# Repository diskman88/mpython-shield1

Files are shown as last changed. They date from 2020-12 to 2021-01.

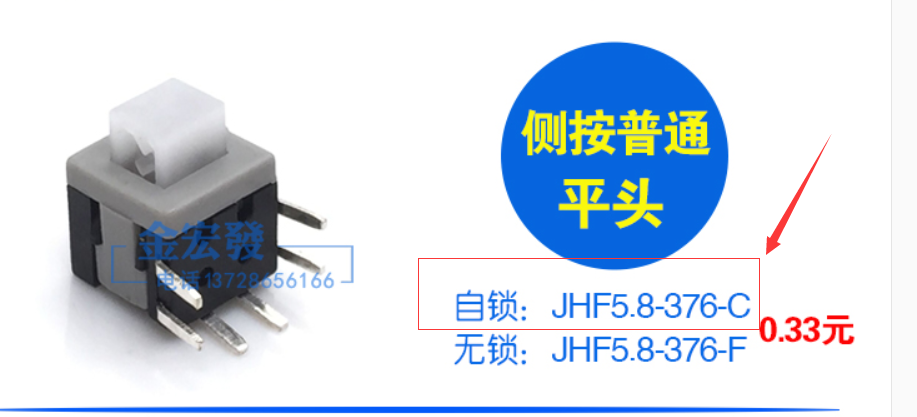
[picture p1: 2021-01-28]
1_Hardware/V2.1.1/datasheet/开关5.png

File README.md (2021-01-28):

# 掌控板拓展板Ⅰ

| 目录 | 说明 | 
| :---  | :---|
| 1_Hardware | 产品原理图及PCB设计工程文件 |
| 2_Firmware | 主从MCU固件源码或bin文件 |
| 3_Software | 配合产品使用或生产用到的软件程序 |
| 4_Examples | 用户应用层相关的源码(含示例) |
| 5_Docs | 产品相关文档(含产品规格书、测试文档)、产品外观结构及包装结构或尺寸图、对外宣传推广效果图片资源  |

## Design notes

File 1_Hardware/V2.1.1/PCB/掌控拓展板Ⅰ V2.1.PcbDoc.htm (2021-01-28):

Reporting Options

# File in Previous Format

Date | : | 2021/1/28
Time | : | 9:38:10
Filename | : | E:\3-micropython\1-esp32\2-掌控扩展板\掌控板扩展板Ⅰ\mpython-shield-1\1_Hardware\V2.1.1\PCB\掌控拓展板Ⅰ V2.1.PcbDoc

Version | Warning

This file was generated by an earlier version of the software

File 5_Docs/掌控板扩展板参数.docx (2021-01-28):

掌控板扩展板参数

片上资源：

板载锂电池，锂电充电电路，音频功放及喇叭输出，DC马达驱动，可外接两个马达，两路I2C输出，12路扩展IO接口。

主要参数：

工作电压：DC3.3V

喇叭最大输出功率：1W

外接DC马达数量：2个

马达最大驱动电流：150mA

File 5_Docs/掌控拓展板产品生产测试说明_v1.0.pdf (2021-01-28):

掌控拓展板

Product Datasheet | 1 | 盛思研发@2017

### 1 概述

掌控拓展板是 mPython 掌控板衍生的一款体积小巧、易于携带。支持电机驱动、语音播放、 语音合成等功能的 IO 引脚扩展板,可扩展 12 路 IO 接口和 2 路 I2C 接口。

### 2 技术参数

该板具有以下特性:

- 驱动工作电压：3.6 ～ 5.2V
- 两路 DC 马达驱动,单路电流 150mA
- 支持音频功放和喇叭输出
- 支持文字转语音(Text To Speech)的语音合成
- 扩展 12 路 IO 接口、2 路 I2C 接口
- 体积小巧、便携,易于携带
- 支持锂电池供电和外接 USB 电源供电两种方式
- 内置 350mAH 锂电池,支持锂电池循环充电
- 工作电压:3.3V
- 最大输出电流: `1A@3.3V`

### 3 生产资料

3.1焊接
需要焊接的有喇叭,电锂电池,排针,压针

要求:
1.焊点饱满,圆润,光滑
2.压针须垂直,无倾斜,位置无偏移.
3.喇叭和电池焊接完成后,须用 3M 胶固定在板上,牢固.

3.2烧录
使用工具:软件 STVP,ST-LINK 烧录器

Step1.打开 stvp,硬件选择 ST-LINK,SWIM,STM8S103F3

Step2.需要烧录 PROGRAM MEMORY 和 OPTION BYTE 两页数据,分别依次加入 STM8S103F3P （TSSOP20)-掌控拓展板 Ⅰ(3.7v) v1.0.hex 和 optionbit.hex

掌控拓展板

Product Datasheet | 2 | 盛思研发@2017

Step3.确认 Memory checksum 是否正确.该固件 checksum 为 PROGRAM MEMORY(0x7A191), PROGRAM MEMORY(0x251)

Step4.选择 program all table,烧录所有页.成功后,提示框提示成功烧录信息.

3.3生产测试
使用工具:烧录架和 usb 电流表
测试项目 | 测试步骤 | 判断条件
喇叭测试 | 1. 将测试板放入测试架上,下压 2. 打开拓展板开关 | 蜂鸣器先发出 1KHz 声音,再(低至高, 高至低)扫频 20hz~20Khz. 要求:声音清脆,无异响,频率正常
电机驱动 | 确认两电机是否转动 | 两电机可转动,并转动力矩有力.
3.3V 电压 | 确认显示屏电压值 | 正确应显示 3.3V,其他均异常
锂电池电压 | 接入 usb 线至拓展板 usb 接口,确 认测试架,电压表显示 | 应能显示锂电池实际电压值,锂电池 电压依实际电池状况而不同,一般在 3.5~4.35V,超出为异常
充电电流 | Usb 线串入电流表插入 usb 接口, 测试针起来,确认电流值 | 电流表显示充电电流值正常,充电电 流依锂电池状态有所不同.具体数据 根据实际生产.
指示灯 | 确认电源,充电指示灯是否正常 | 指示灯可亮

### 4 修订版本

Version | Note | Date
V1.0 | 初定 | 2019.03.05

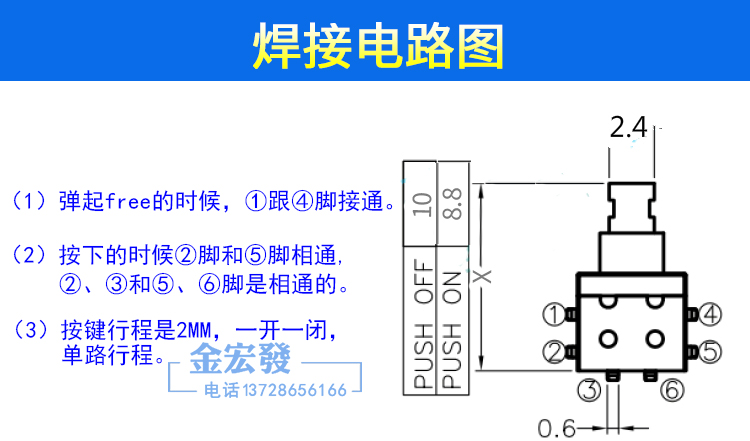
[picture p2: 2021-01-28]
1_Hardware/V2.1.1/datasheet/电源开关3.jpg

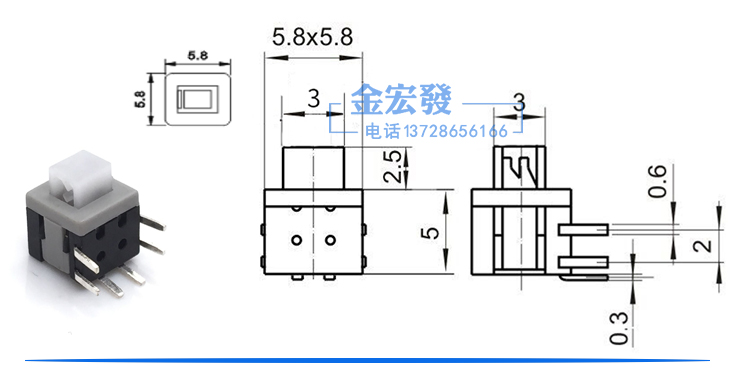
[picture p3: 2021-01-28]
1_Hardware/V2.1.1/datasheet/电源开关4.jpg

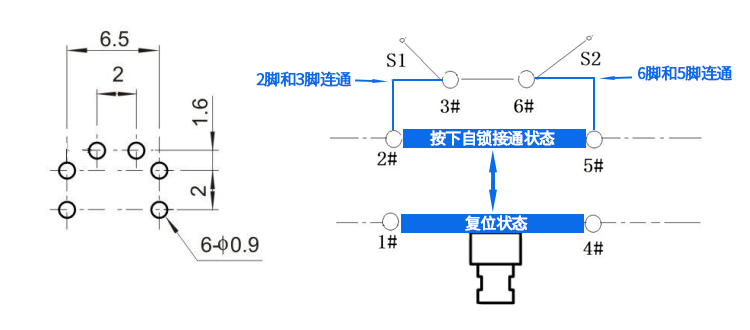
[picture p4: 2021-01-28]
1_Hardware/V2.1.1/datasheet/电源开关5.jpg

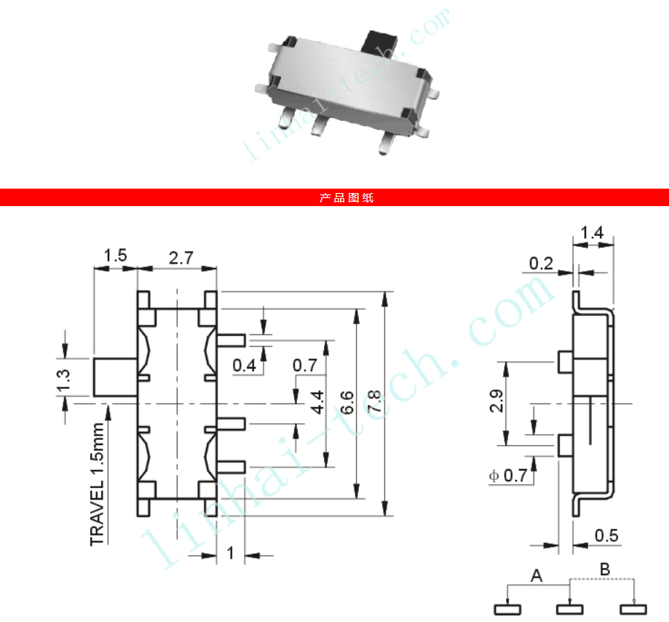
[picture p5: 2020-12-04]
1_Hardware/V2.1.1/datasheet/拨动开关.png

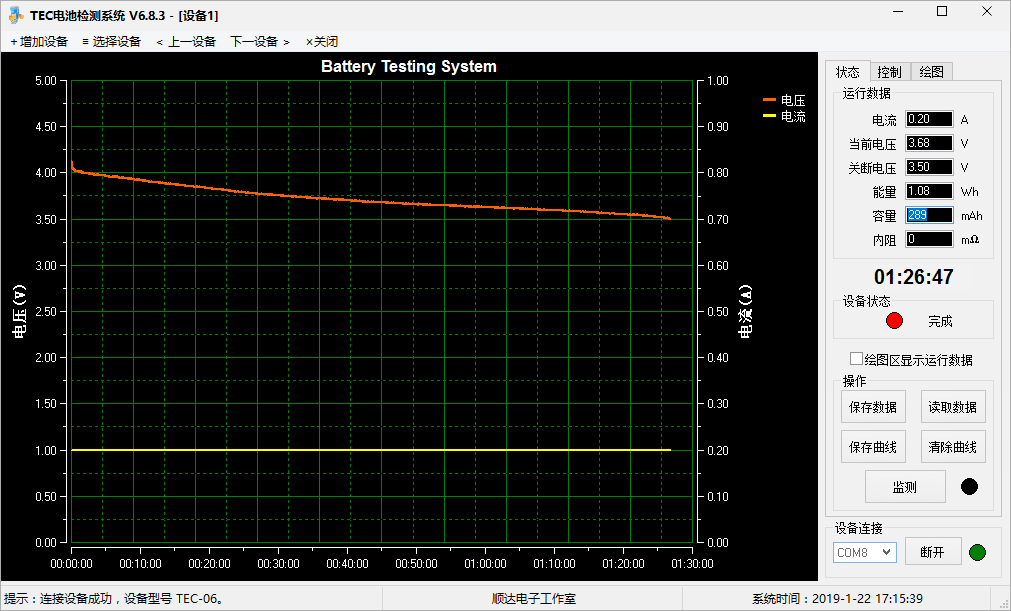
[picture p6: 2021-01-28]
5_Docs/华为电池2.png

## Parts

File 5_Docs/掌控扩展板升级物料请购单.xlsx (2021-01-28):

单号：
盛思工厂
手工请购单
页次：
1/1
单据日期： 2020-12-28 申请人： 蒋朝晖 审核码： 已审核 请购日期： 2020-12-28 申请部门： 研发二部 请购类型： 其他
序号 | 品号 | 品名 | 规格 | 请购数量 | 请购单 位 | 需求日期 | 紧急 | 参考供应商
1 | 50090 | 三极管 | 型号：MMBT3906LP-7 PNP 集电极最大工作电流：200mA 集射极击穿电压Vce:40V 封装：DFN-3L | 100 | PCS | 2021-01-02 |  | https://so.szlcsc.com/global.html?k=MMBT3906%2520DFN&hot-key=%E9%92%BD%E7%94%B5%E5%AE%B9TC212A106K016Y
仓库：
制单：
核准：

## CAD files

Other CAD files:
2_Firmware/发布固件/STM8S103F3P（TSSOP20)-掌控拓展板 Ⅰ(3.8v) 固件_v2.1.0/STM8S103F3P（TSSOP20)-掌控拓展板 Ⅰ(3.8v) v2.1.0.stp

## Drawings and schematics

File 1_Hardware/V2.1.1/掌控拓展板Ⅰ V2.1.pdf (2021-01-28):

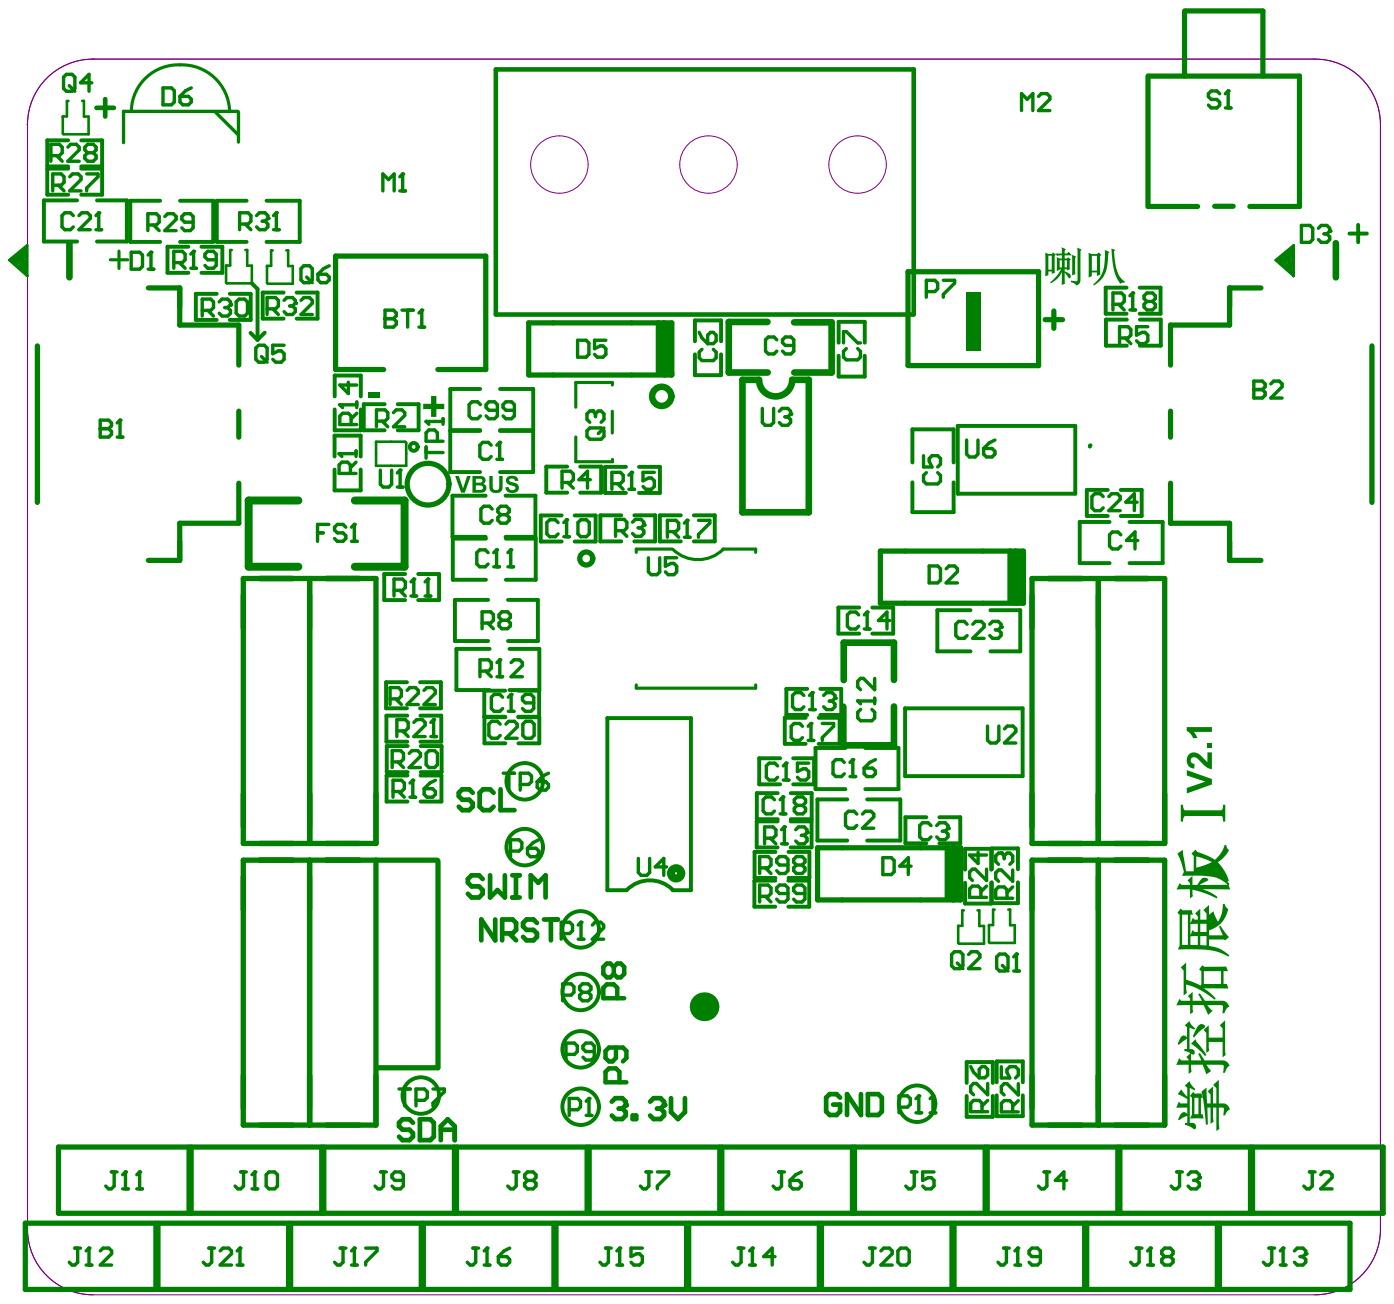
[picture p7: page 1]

Board St

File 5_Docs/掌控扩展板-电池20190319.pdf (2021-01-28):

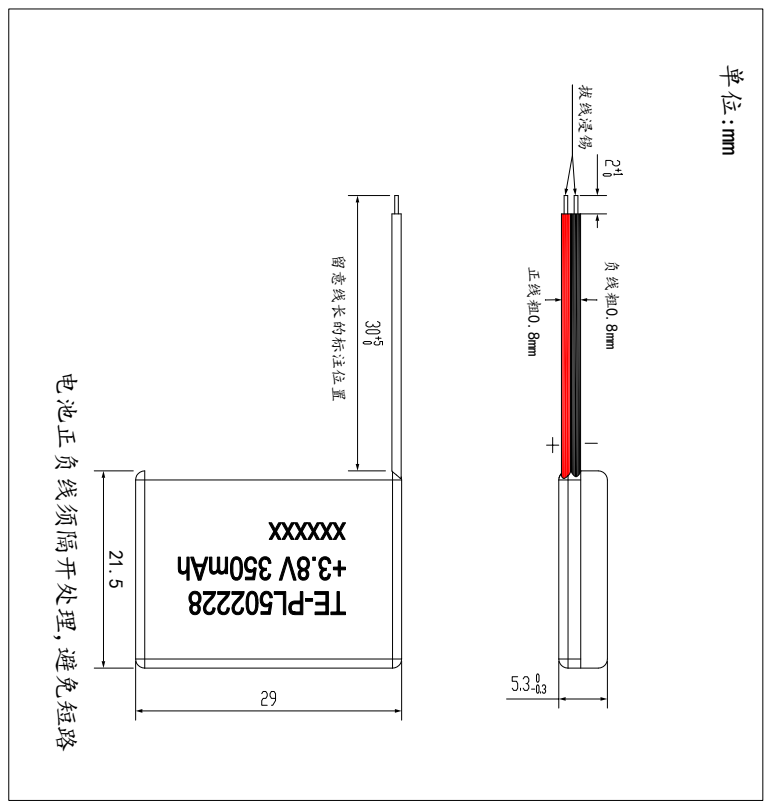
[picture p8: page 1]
留意线长的标注位置; 拔线浸锡; 电池正负线须隔开处理,避免短路; 负线粗0.8mm; 正线粗0.8mm

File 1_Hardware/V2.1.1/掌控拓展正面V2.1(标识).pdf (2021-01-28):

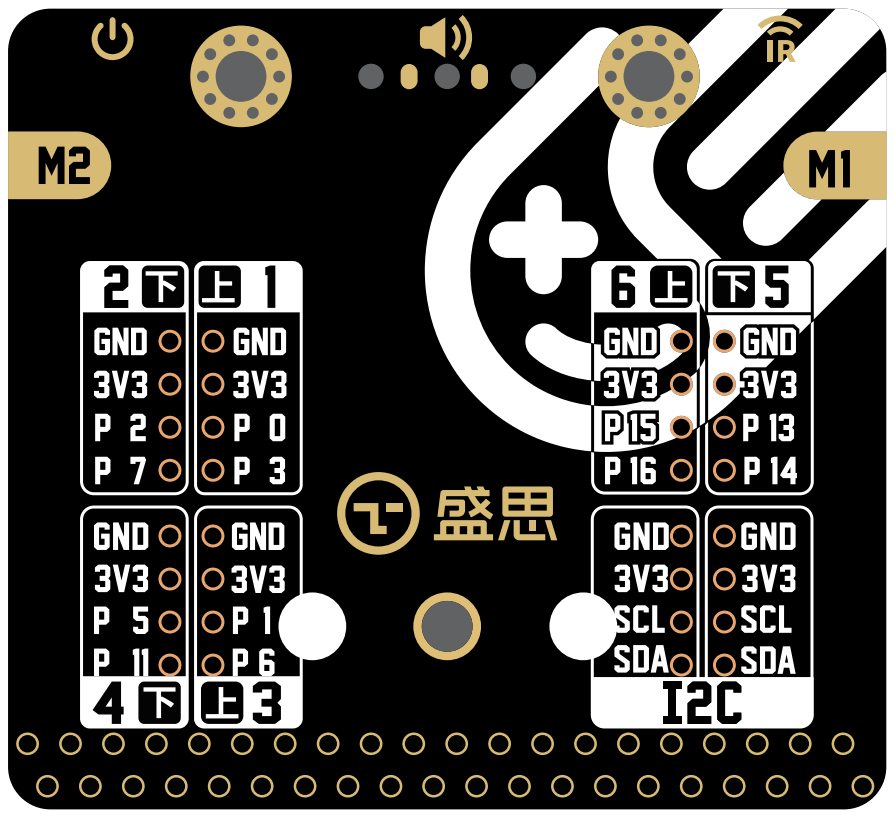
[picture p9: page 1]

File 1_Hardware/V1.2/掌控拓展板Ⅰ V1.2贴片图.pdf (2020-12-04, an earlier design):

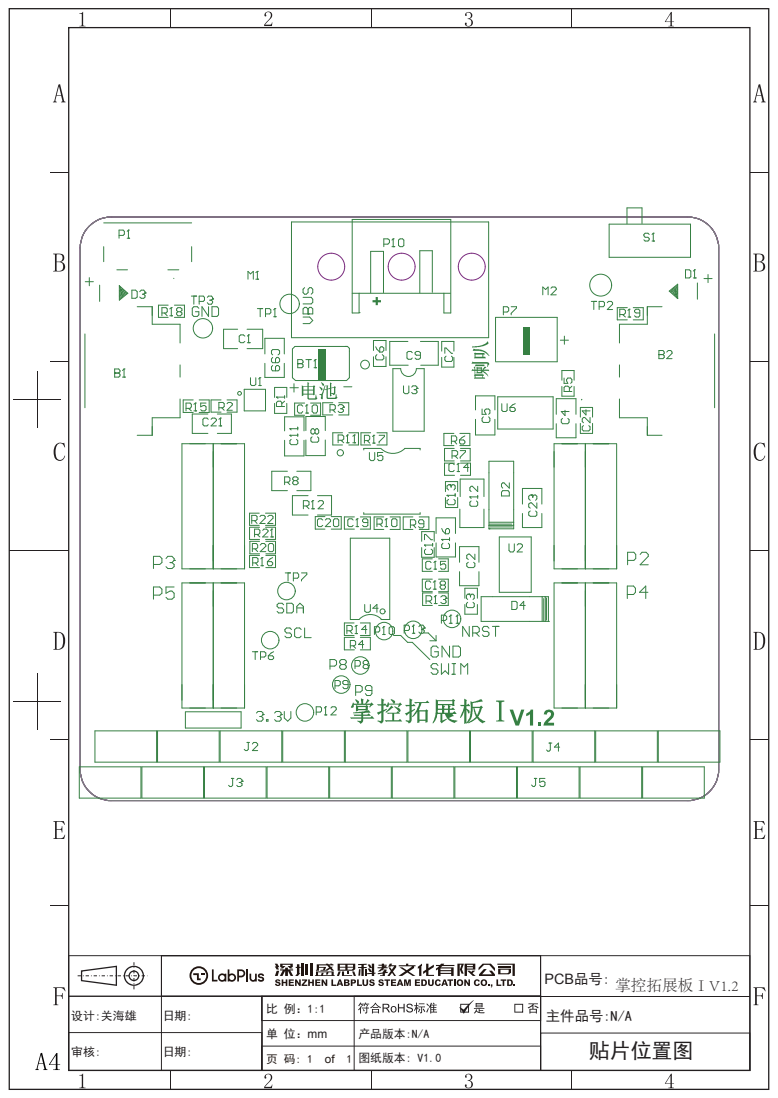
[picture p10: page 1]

PCB品号: 掌控拓展板ⅠV1.2

设计:关海雄 | 日期: | 比 例：1:1 | | | 主件品号:N/A

单 位：mm | 产品版本:N/A

审核: | 日期: | 贴片位置图

页 码: 1 of 1 | 图纸版本: V1.0

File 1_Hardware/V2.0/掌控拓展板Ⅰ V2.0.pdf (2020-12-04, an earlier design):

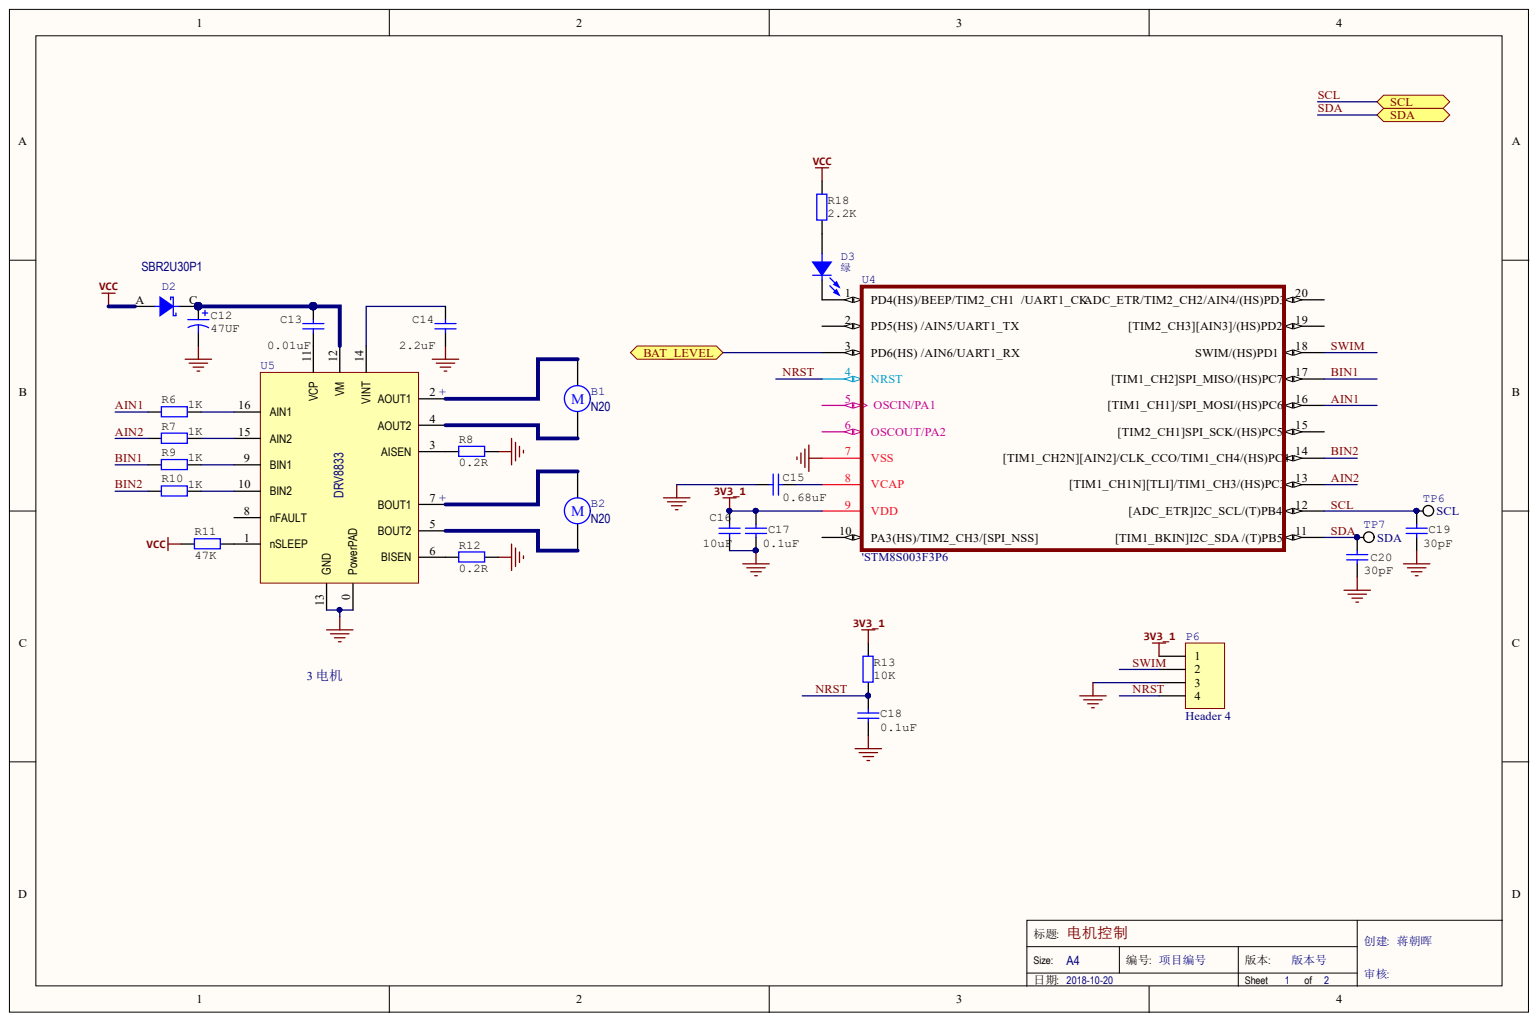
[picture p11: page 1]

电 机 控 制 标题 : | 创建 : 蒋朝晖 审核 :

Size: A4 | 编号 : 项目编号 | 版本 : 版本号

日期 : 2018-10-20 | | Sheet of

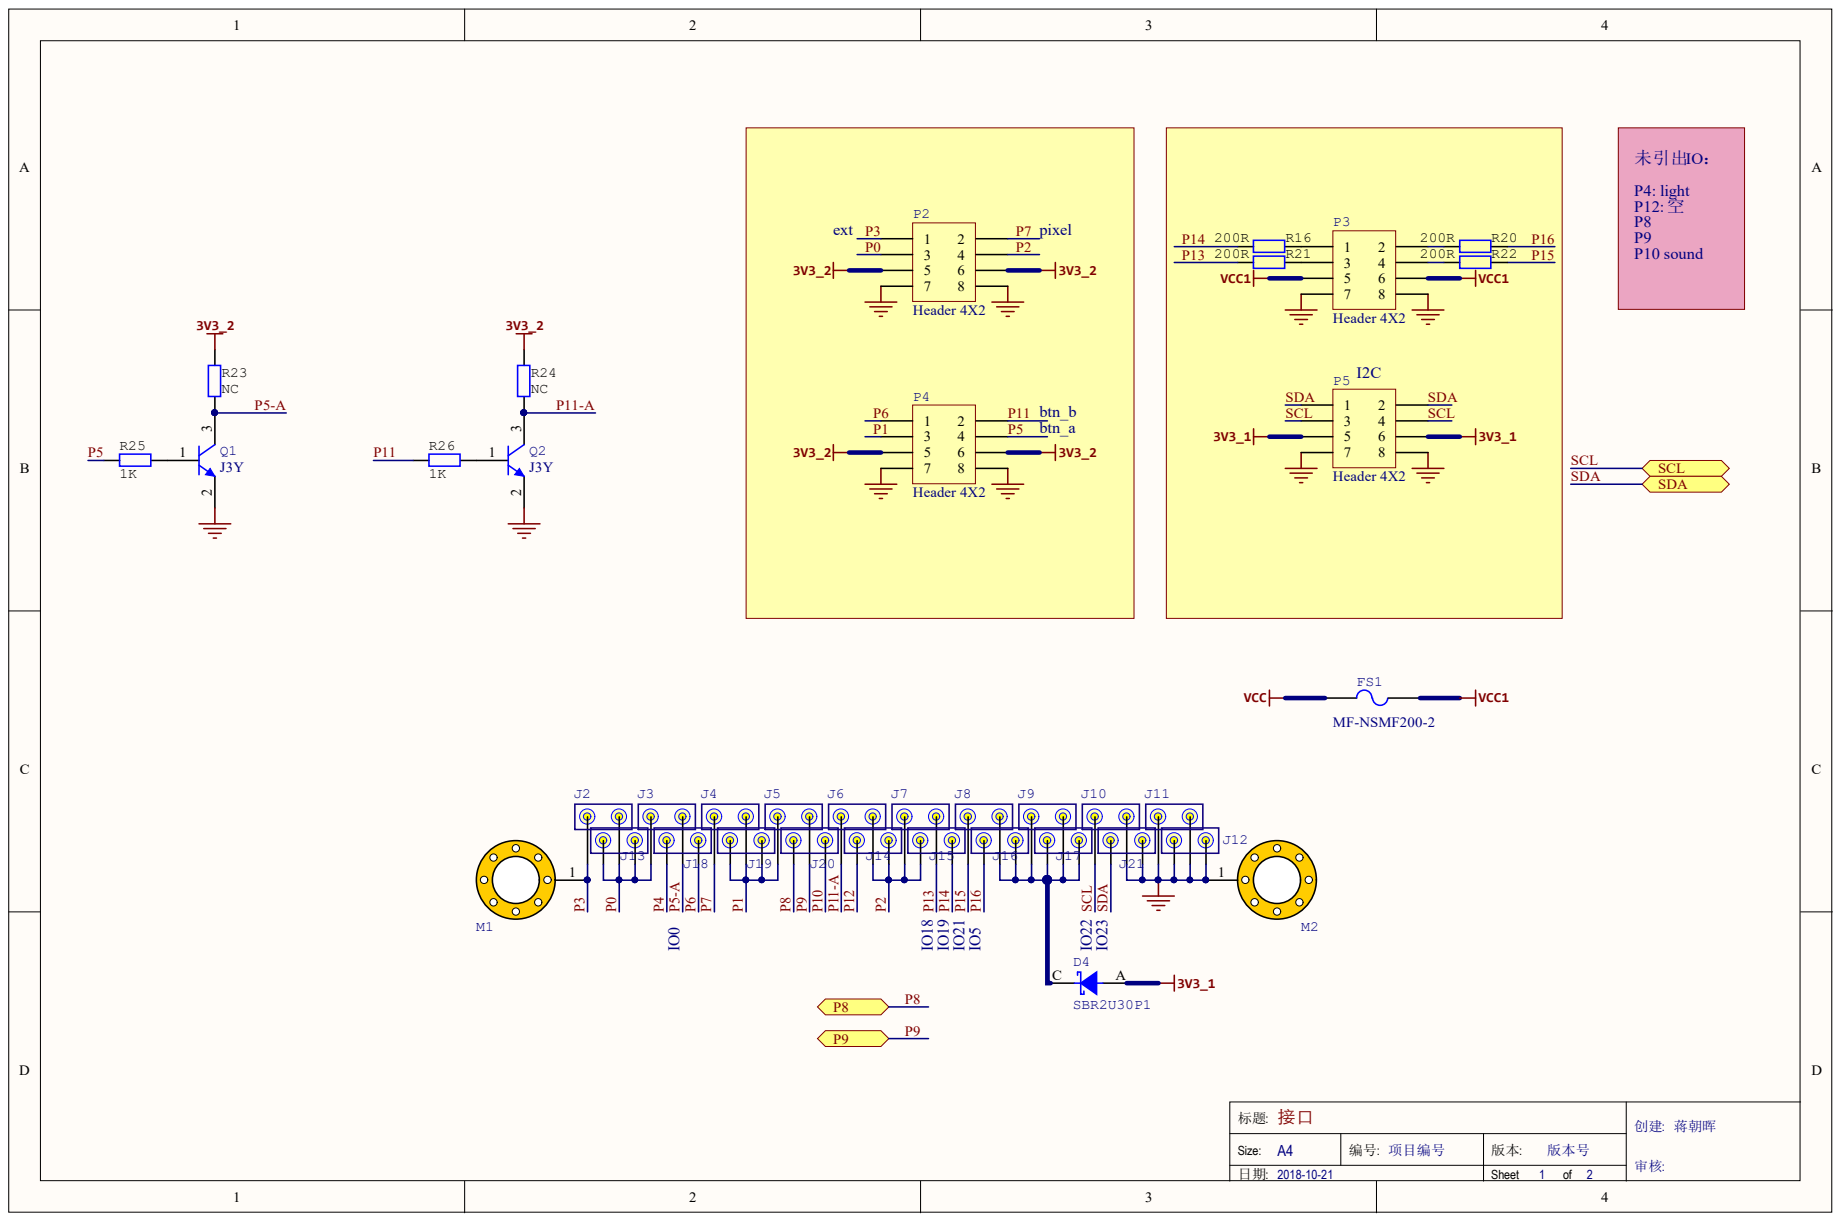
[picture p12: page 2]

接口 标题: | 创建: 蒋朝晖

Size: A4 | 编号: 项目编号 | 版本: 版本号
日期: | | | 审核: 2

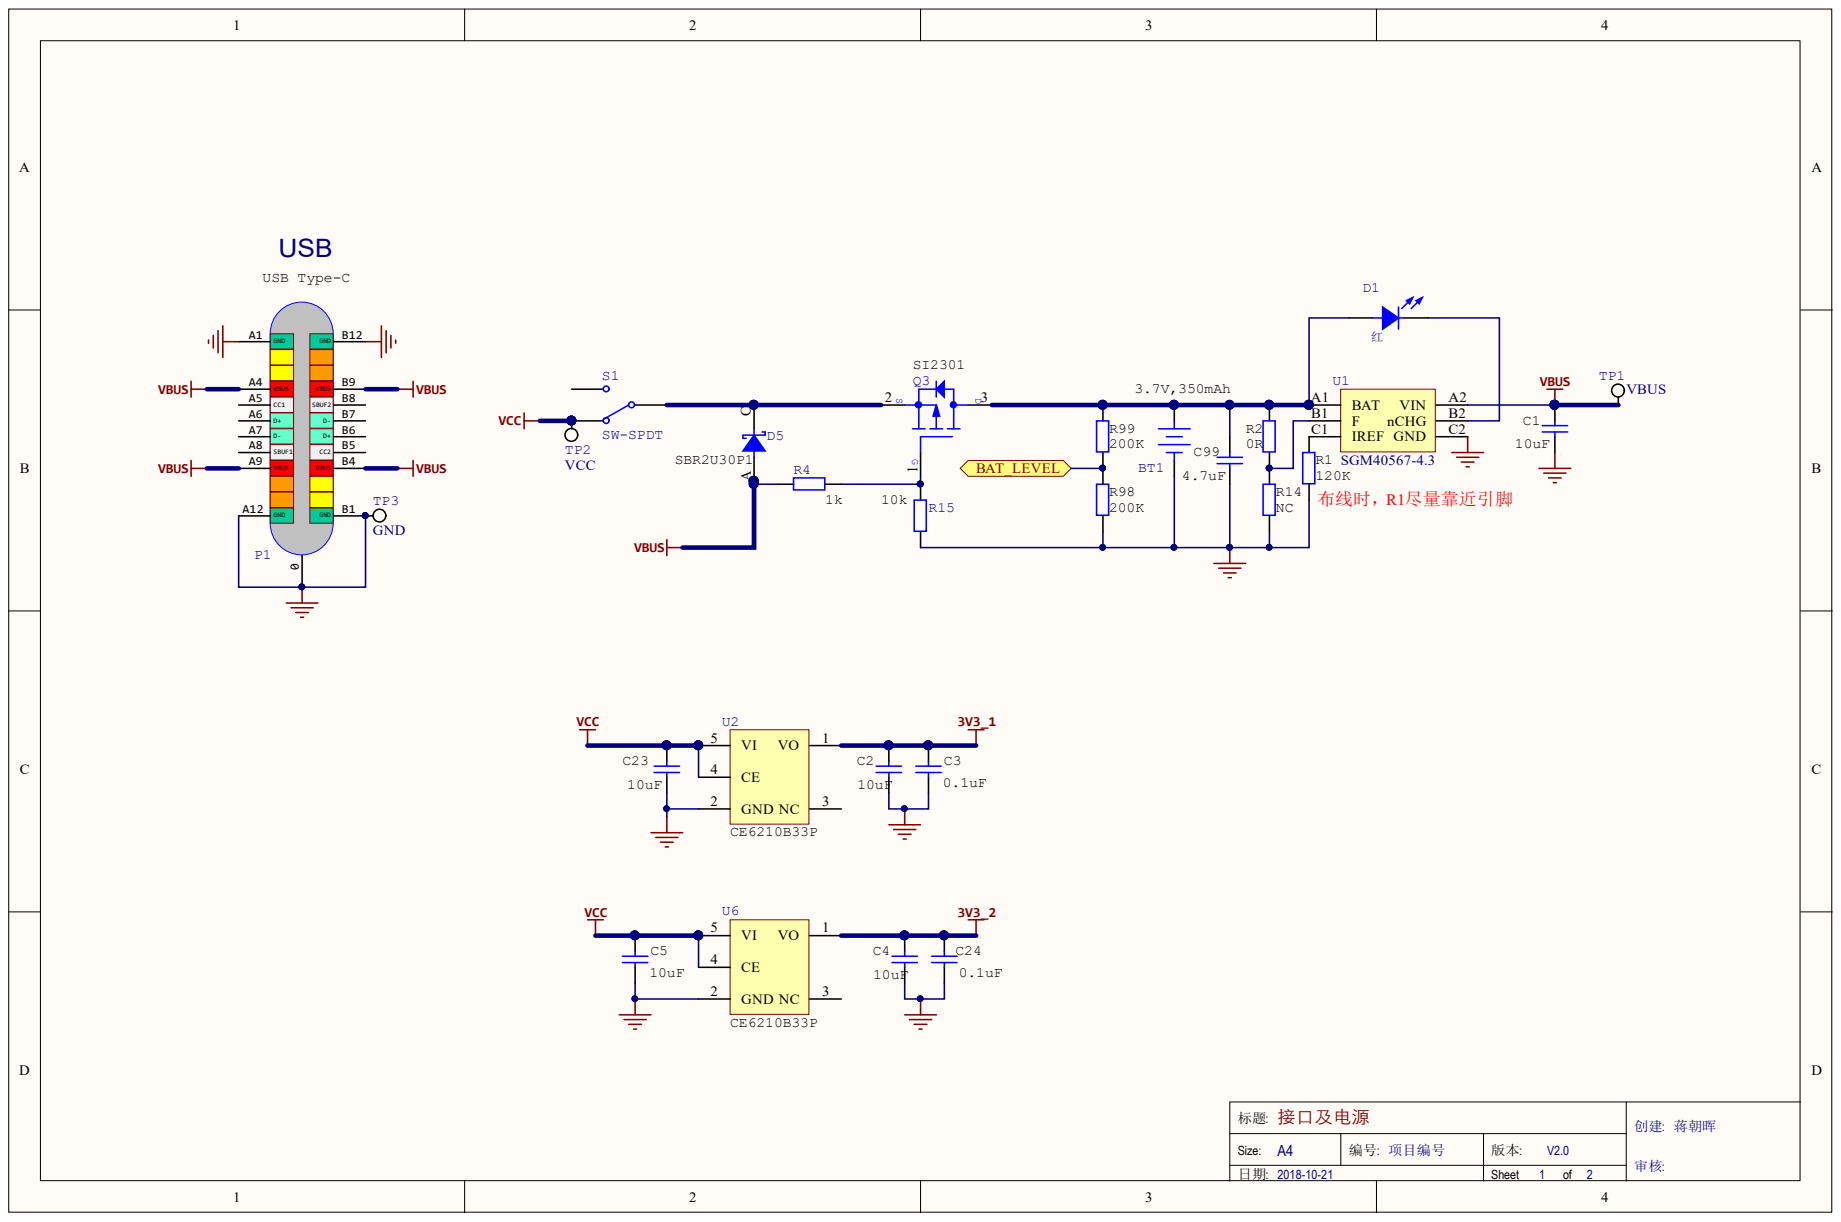
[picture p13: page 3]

接口及电源 标题: | 创建: 蒋朝晖

Size: A4 | 编号: 项目编号 | 版本: V2.0
日期: | | | 审核: 2

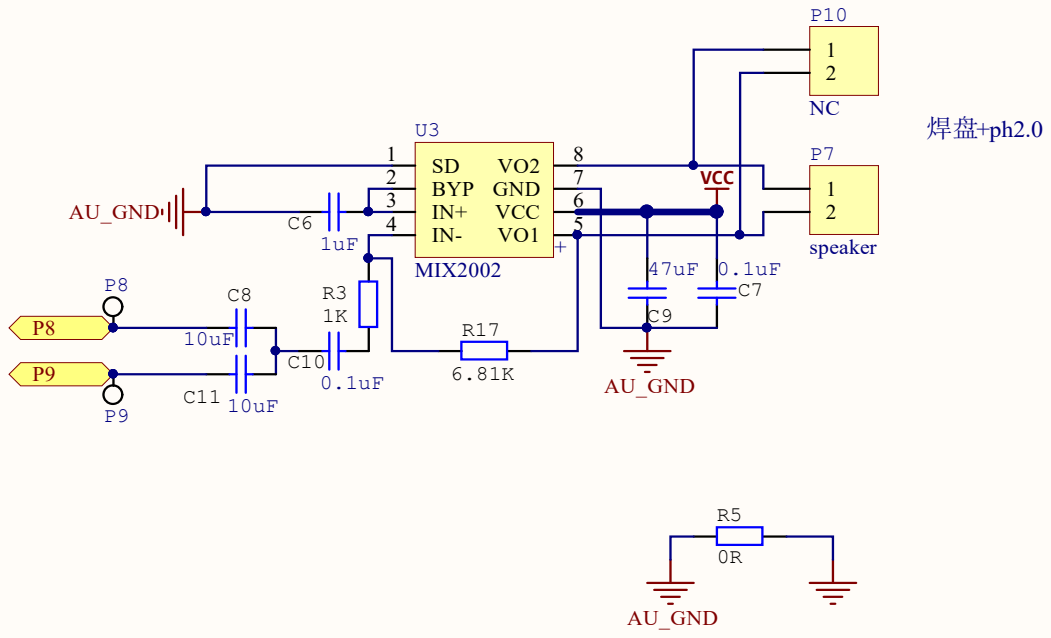
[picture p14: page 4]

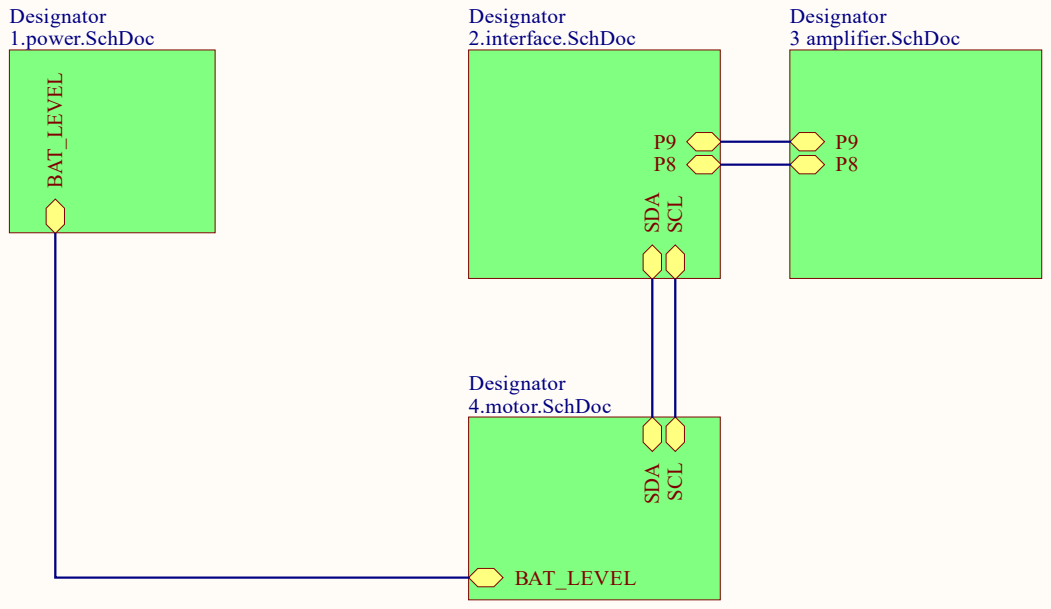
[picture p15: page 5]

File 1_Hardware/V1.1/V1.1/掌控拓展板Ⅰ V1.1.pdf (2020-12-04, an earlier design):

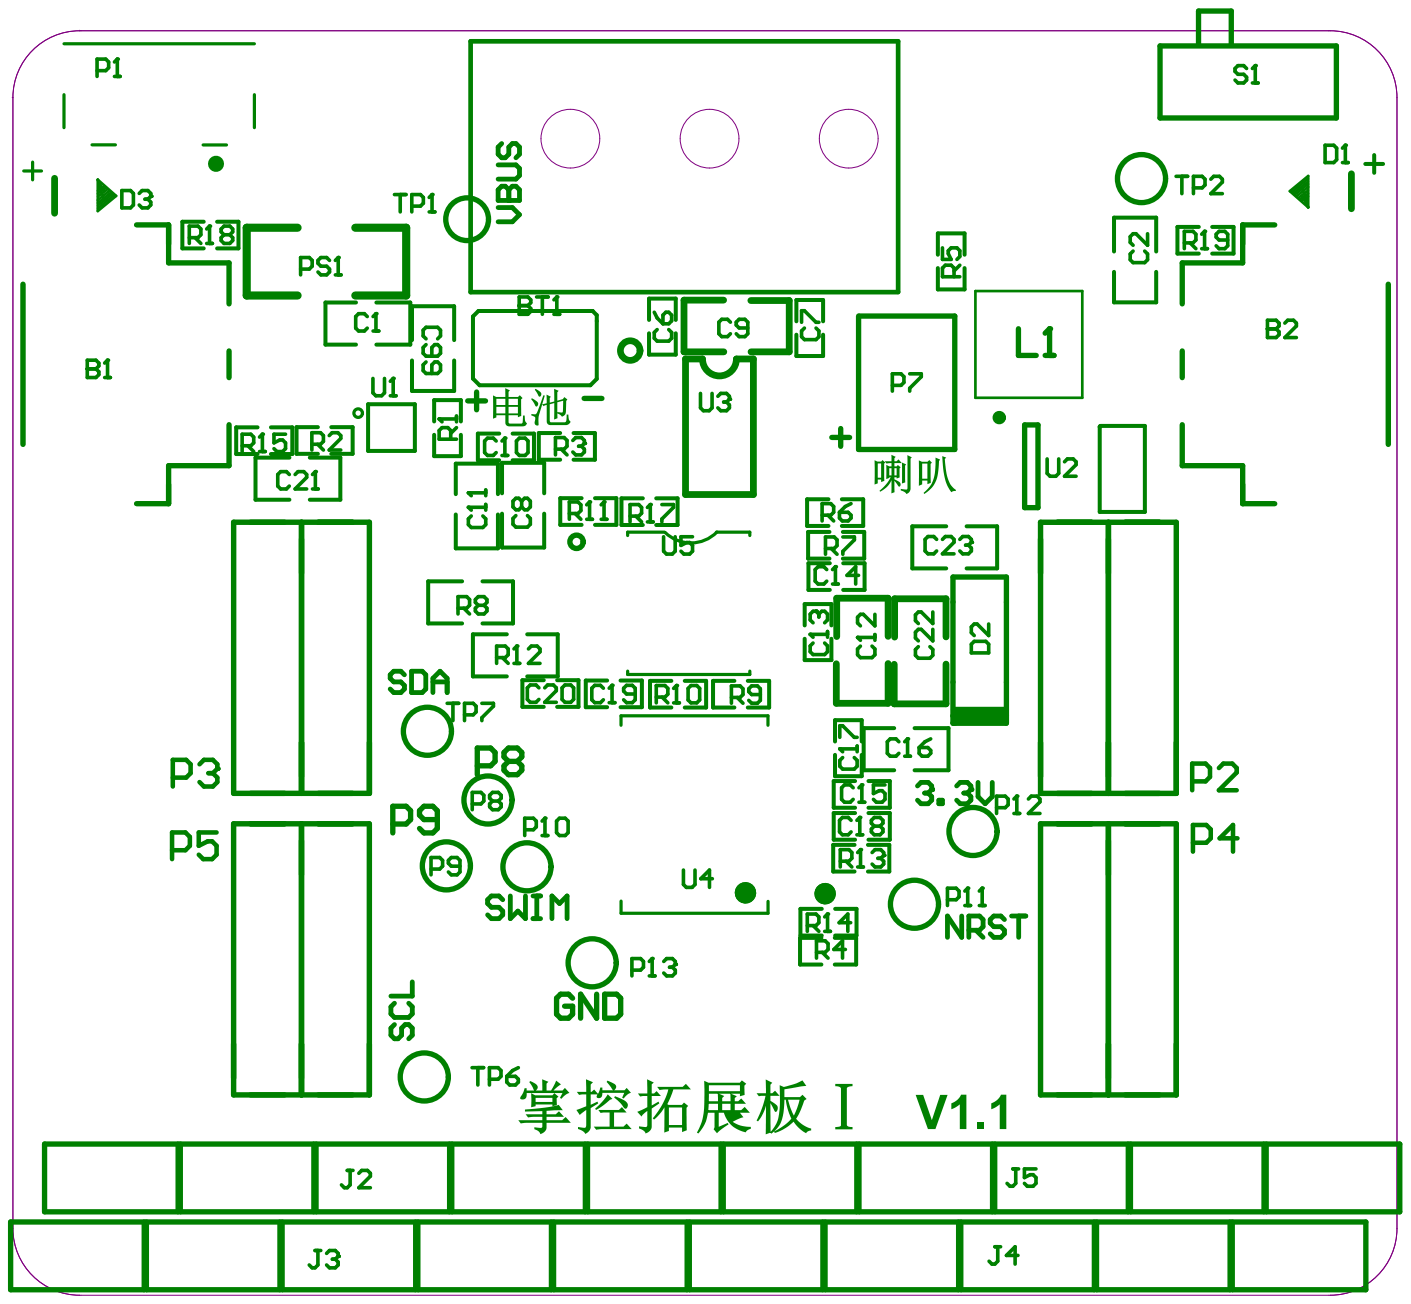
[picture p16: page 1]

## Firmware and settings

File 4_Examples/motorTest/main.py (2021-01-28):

from mpython import *
from shield import *
import time
import struct

# test
ir_code = IR_encode()
ir = IR()

# 示例1 发送NEC编码
# 参数1：用户码 参数2：命令码
ir_buff = ir_code.encode_nec(0x01,0x55)
while True:
    ir.send(ir_buff, repeat_en = 1)
    time.sleep_ms(3000)
    ir.stop_send()
    time.sleep_ms(3000)
    # set_speed(1,100)
    # set_speed(2,100)
    # time.sleep_ms(2000)
    # set_speed(1,-100)
    # set_speed(2,-100)
    # time.sleep_ms(2000)

# 示例2 编码学习
key_pressed = False
key_pressed1 = False

def on_button_b_down(_):
    global key_pressed
    time.sleep_ms(10)
    if button_b.value() == 1: return
    key_pressed = True

button_b.irq(trigger=Pin.IRQ_FALLING, handler=on_button_b_down)

def on_button_a_down(_):
    global key_pressed1
    time.sleep_ms(10)
    if button_a.value() == 1: return
    key_pressed1 = True

button_a.irq(trigger=Pin.IRQ_FALLING, handler=on_button_a_down)

buff = bytearray()
learn_successed = False

while True:
    if key_pressed:
        key_pressed = False      
        rgb[0] = (int(255), int(0), int(0))
        rgb.write()
        ir.start_learn()
        time.sleep(4) # 须在4秒内按住遥控灯灭后松开
        rgb[0] = (int(0), int(0), int(0))
        rgb.write()
        status = ir.get_learn_status()
        if(status == 0): # 学习成功
            buff = ir.get_learn_data() # 获取学习的按键参数。
            learn_successed = True
            oled.fill(0)
            oled.DispChar('success.', 10, 10, 1)
            oled.show()
            print(struct.unpack('>H2B16H', buff))
            # print(buff)
        else:
            learn_successed = False
            oled.fill(0)
            oled.DispChar('false.', 10, 10, 1)
            oled.show()
    # print(learn_successed)
    if key_pressed1:
        key_pressed1 = False;
        print("send")
        if learn_successed:
            ir.send(buff, 1)  # 利用学到的按键参数发码。
            time.sleep_ms(1000)
            ir.stop_send()
      
# 示例3：发送philip RC-6编码（暂有问题，时序整理有问题）
#           lead
# MN6014_C5D6_code = [3376, 3376, 844, 844, 844, 1688, 0, 0, 0, 0, 0, 0, 0, 0, 0, 0]
# MN6014_C5D6_data = [0, 
#                     1, 1, 1, 1, 2, 
#                     1, 1, 1, 1, 1, 2, 
#                     2, 2, 2, 2, 1, 
#                     2, 2, 2, 2, 2, 1, 
#                     ]
# buff = ir_code.encode_raw(38000, 23, 22, MN6014_C5D6_code, MN6014_C5D6_data)
# while True:
#     ir.send(buff)
#     time.sleep_ms(200)

# def start():
#     rgb[0] = (int(255), int(0), int(0))
#     rgb.write()
#     ir.start_learn()
#     time.sleep(4) # 须在4秒内按住遥控灯灭后松开
#     rgb[0] = (int(0), int(0), int(0))
#     rgb.write()
#     status = ir.get_learn_status()
#     print(status)

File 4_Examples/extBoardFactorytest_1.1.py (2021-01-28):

from mpython import *
import parrot
from machine import Timer

volt = ADC(Pin(Pin.P0))


# 喇叭测试
def speaker():
    p8 = PWM(Pin(Pin.P8), freq=1000, duty=512)
    p9 = PWM(Pin(Pin.P9), freq=1000, duty=512)
    sleep(2)
    p8.duty(0)
    p9.duty(0)
    p8 = PWM(Pin(Pin.P8), freq=0, duty=512)
    for i in range(20, 20000, 200):
        p8.freq(i)
        print(i)
        sleep_ms(20)
    p8.duty(0)
    sleep_ms(200)
    p9 = PWM(Pin(Pin.P9), freq=20000, duty=512)
    for i in range(20000, 20, -200):
        p9.freq(i)
        print(i)
        sleep_ms(20)
    p9.duty(0)
    sleep_ms(200)
    sleep(1)
    p8.duty(0)
    p9.duty(0)


dc_status = False


def driver_test(_):

    global dc_status
    if dc_status:
        parrot.set_speed(parrot.MOTOR_1, 100)
        parrot.set_speed(parrot.MOTOR_2, 100)
    else:
        parrot.set_speed(parrot.MOTOR_1, -100)
        parrot.set_speed(parrot.MOTOR_2, -100)
    dc_status = not dc_status


rgb.fill((
    0,
    0,
    0,
))
rgb.write()

oled.DispChar("扬声器测试", 40, 15)
oled.DispChar("1KHz信号+扫频", 20, 30)

oled.show()
speaker()

oled.fill(0)
tim1 = Timer(1)

tim1.init(period=2000, mode=Timer.PERIODIC, callback=driver_test)

while True:
    value = volt.read() * 3.3 / 4095
    oled.DispChar("电机：2秒循环正反转", 0, 0)
    oled.DispChar("电压值：%0.2f" % value, 0, 20)
    oled.DispChar("usb接口:用usb电流表", 0, 35)
    oled.show()

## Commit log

2020-12-04 New project.
    [1.power.SchDoc, 2.interface.SchDoc, 3 amplifier.SchDoc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]
2021-01-18 拓展板产测程序
2021-01-26 上传V2.1 PCB文件
    [掌控拓展板Ⅰ.PrjPcb]
2021-01-28 升级到v2.1.0
    [1.power.SchDoc, 2.interface.SchDoc, 3 amplifier.SchDoc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]
2021-01-28 固件升级到v2.1.0
